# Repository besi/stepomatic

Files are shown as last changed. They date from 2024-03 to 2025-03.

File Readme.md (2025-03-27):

# Stepomatic

Wifi-enabled 28BYJ-48 stepper motor driver.

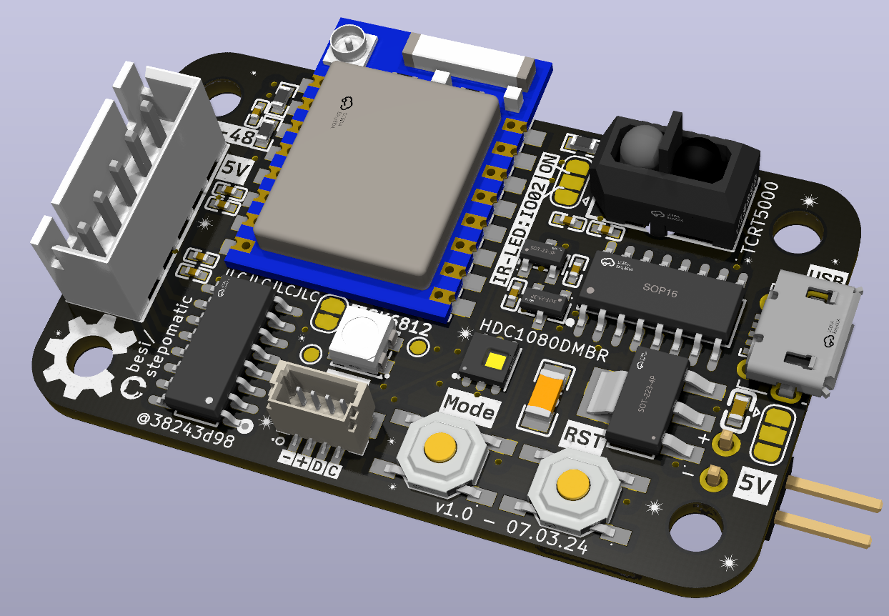
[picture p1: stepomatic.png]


## Pinout

| Function | Pin |
|:---|---:|
| Motor 1 | 13 |
| Motor 2 | 12 |
| Motor 3 | 14 |
| Motor 4 | 15 |
| SDA | 4 |
| SCL | 5 |
| Mode | 0 |
| Neopixel | 16 |
| Enable IR  | 2 |
| Distance | ADC(0) |

The IR diode can be enabled by pulling `IO2` to `0`.

The SDA and SCL need to be pulled high in software.

## Flashing

The used ESP-07 chip uses 1MB of flash so make sure to flash it with the [1MB flash image](https://micropython.org/download/ESP8266_GENERIC/).

## JLC Componennts

    # Put this in your ~/.zshrc or ~/.bashrc
    alias jlc='JLC2KiCadLib -dir lib'
    
    # Now the following will download kicad symbols, footprints and 3d models
    jlc C82227

## Acknowledgments

- Special thanks to Valentyna M. for designing the pcb artwork.
- The free font [Dexotick](https://www.behance.net/dhanstudio) was used for the pcb artwork.
- [JLC2KiCadLib](https://pypi.org/project/JLC2KiCadLib) was used for downloading the footprints for the LCSC footprints

## Known issues

The Neopixel on Pin 16 does not work since that Pin has some limitations and neither supports PWM or I2C.

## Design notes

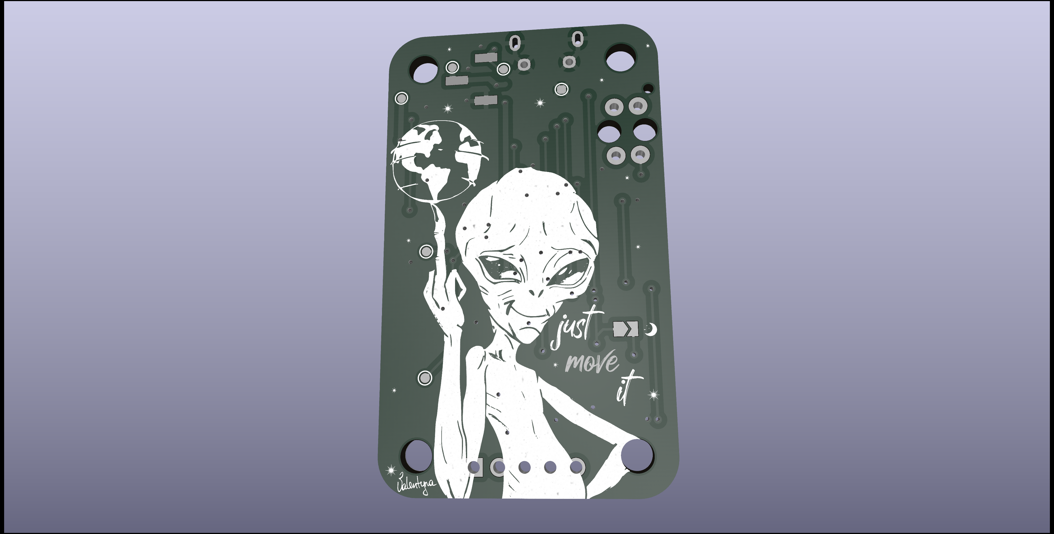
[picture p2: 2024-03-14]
stepomatic-back.png

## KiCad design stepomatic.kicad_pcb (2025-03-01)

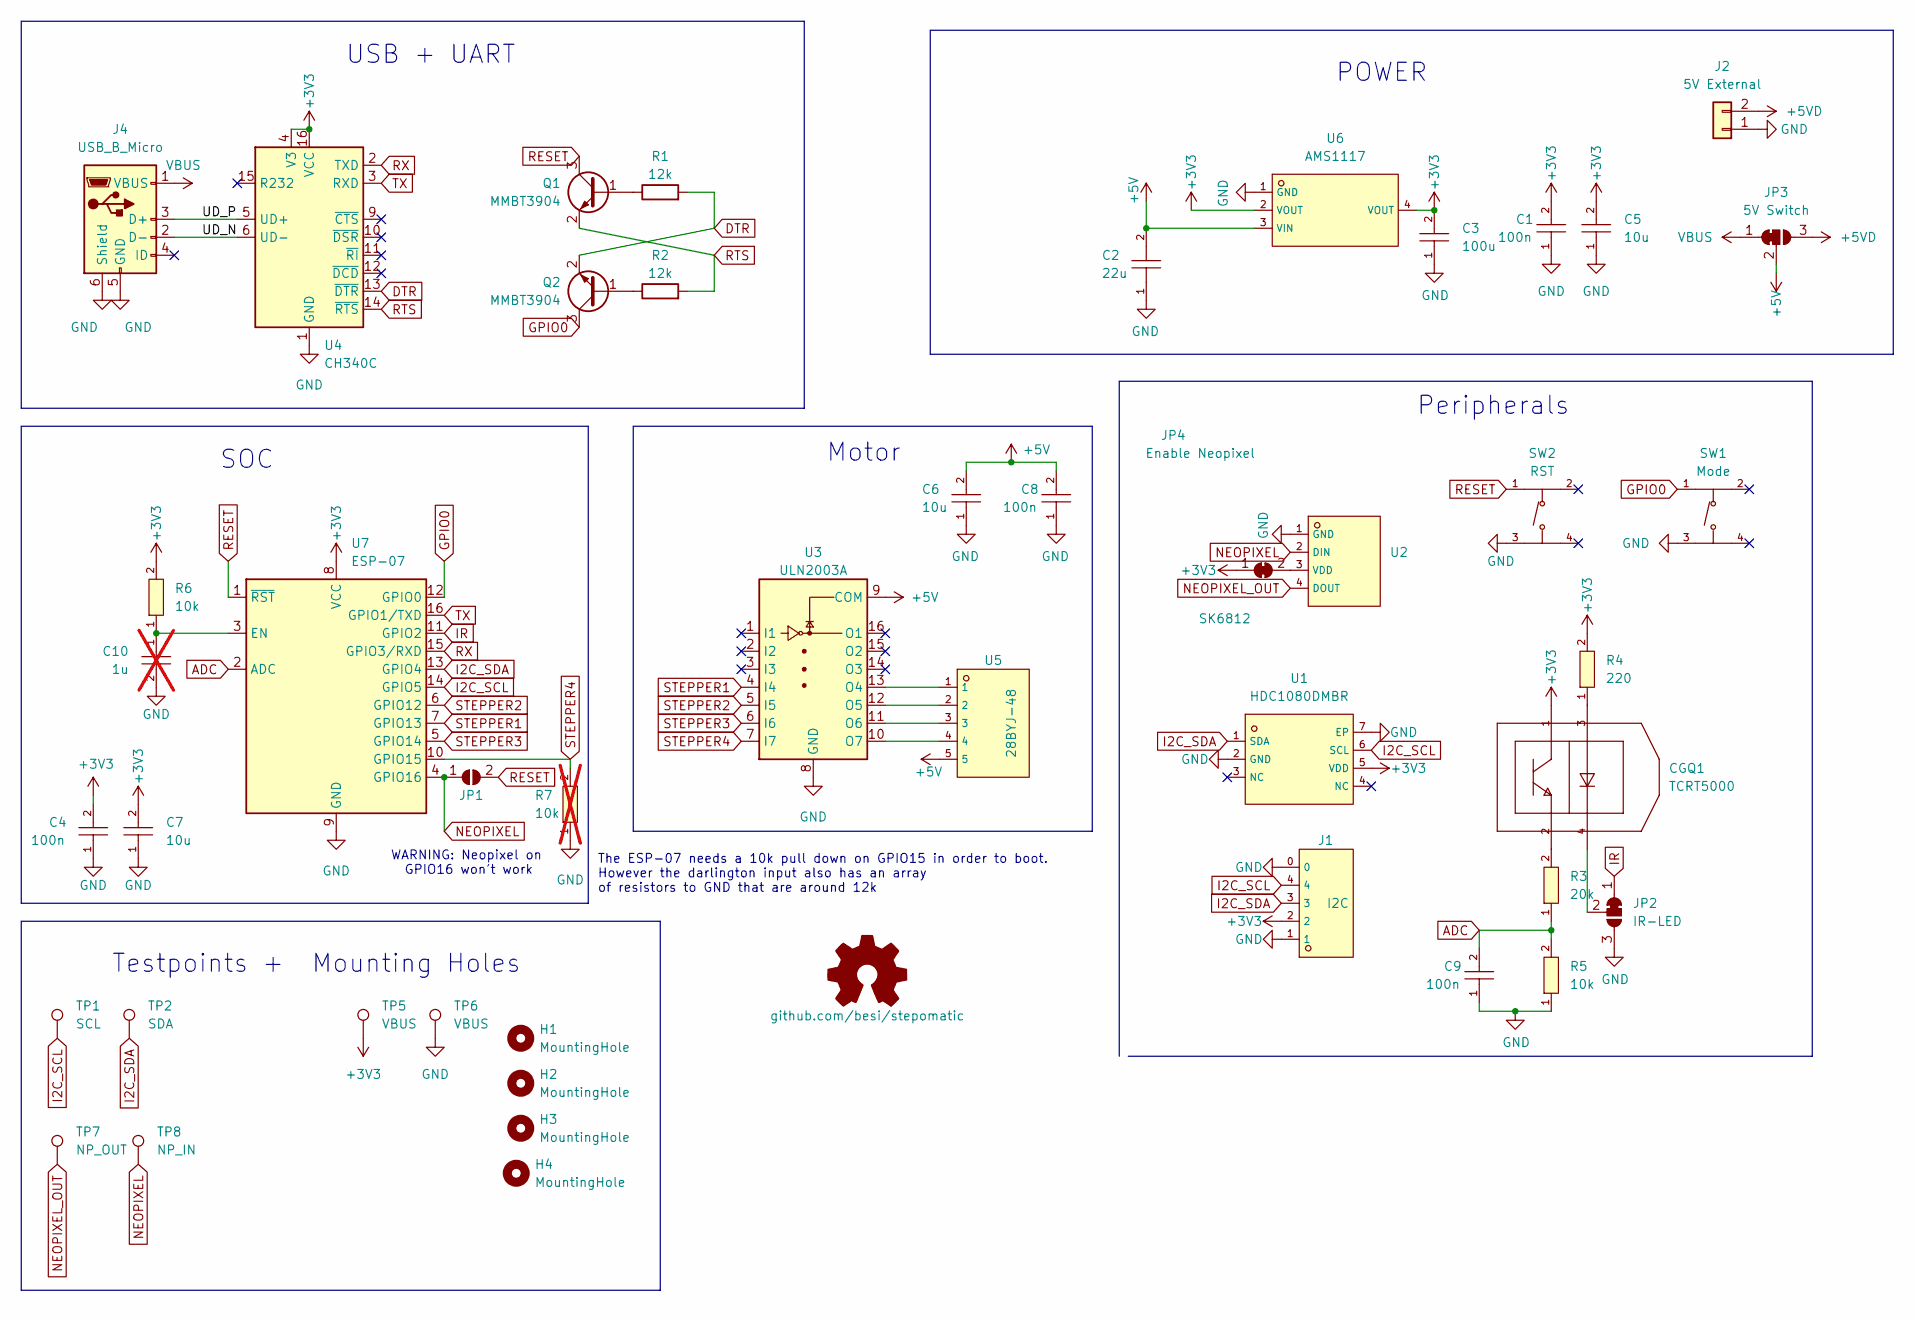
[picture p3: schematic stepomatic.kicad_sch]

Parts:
C1, C4, C8, C9: 100n; C0402; LCSC C1525
C2: 22u; C0603; LCSC C59461
C3: 100u; C1206; LCSC C15008
C5, C6, C7: 10u; C0402; LCSC C15525
C10: 1u; C0603; LCSC C15849; not fitted
CGQ1: TCRT5000; OPTO-TH_TCRT5000L; LCSC C24085
H1, H2, H3, H4: MountingHole; MountingHole_3.2mm_M3; LCSC DNP
J1: I2C; CONN-SMD_BM04B-SRSS-TB; LCSC C160390
J2: 5V External; PinHeader_1x02_P2.54mm_Horizontal
J4: USB_B_Micro; USB_Micro-B_Molex-105017-0001; LCSC C505111
JP1: Deep Sleep; SolderJumper-2_P1.3mm_Open_TrianglePad1.0x1.5mm; LCSC DNP
JP2: IR-LED; SolderJumper-3_P1.3mm_Bridged12_RoundedPad1.0x1.5mm
JP3: 5V Switch; SolderJumper-3_P1.3mm_Bridged12_RoundedPad1.0x1.5mm
JP4: Enable Neopixel; SolderJumper-2_P1.3mm_Bridged_RoundedPad1.0x1.5mm
OSHW1: github.com/besi/stepomatic; OSHW-Symbol_6.7x6mm_SilkScreen
Q1, Q2: MMBT3904; SOT-23-3_L2.9-W1.3-P1.90-LS2.4-BR; LCSC C20526
R1, R2: 12k; C0402; LCSC C25752
R3: 20k; R0603; LCSC C4184
R4: 220; R0603; LCSC C22962
R5, R6: 10k; R0603; LCSC C25804
R7: 10k; R0603; LCSC C25804; not fitted
SW1: Mode; SW-SMD_4P-L5.1-W5.1-P3.70-LS6.5-TL-2; LCSC C318884
SW2: RST; SW-SMD_4P-L5.1-W5.1-P3.70-LS6.5-TL-2; LCSC C318884
TP1: SCL; TestPoint_Pad_D1.0mm
TP2: SDA; TestPoint_Pad_D1.0mm
TP5, TP6: VBUS; TestPoint_Pad_D1.0mm
TP7: NP_OUT; TestPoint_Pad_D1.0mm
TP8: NP_IN; TestPoint_Pad_D1.0mm
U1: HDC1080DMBR; SENSOR-SMD_HDC1080DMBR; LCSC C82227
U2: SK6812; LED-SMD_4P-L3.5-W3.5-BR_SK6812MINI-HS; LCSC C2922787
U3: ULN2003A; SOIC-16_L9.9-W3.9-P1.27-LS6.0-BL; LCSC C7512
U4: CH340C; SOP-16_L10.0-W3.9-P1.27-LS6.0-BL; LCSC C7464026
U5: 28BYJ-48; CONN-TH_B5B-XH-A-LF-SN; LCSC C157991
U6: AMS1117; SOT-223-3_L6.5-W3.4-P2.30-LS7.0-BR; LCSC C6186
U7: ESP-07; WIFIM-SMD_ESP-07; LCSC C82894

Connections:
+3V3: C1.2, C3.2, C4.2, C5.2, C7.2, CGQ1.1 (C), J1.2, JP4.1 (A), R4.2, R6.2, TP5.1, U1.5 (VDD), U4.4 (V3), U4.16 (VCC), U6.2 (VOUT), U6.4 (VOUT), U7.8 (VCC)
+5V: C2.2, C6.2, C8.2, JP3.2 (C), U3.9 (COM), U5.5, U6.3 (VIN)
+5VD: J2.2, JP3.3 (B)
/UD_N: J4.2 (D-), U4.6 (UD-)
/UD_P: J4.3 (D+), U4.5 (UD+)
ADC: C9.2, R3.1, R5.2, U7.2 (ADC)
DTR: Q2.2 (E), R1.2, U4.13 (~DTR)
GND: C1.1, C2.1, C3.1, C4.1, C5.1, C6.1, C7.1, C8.1, C9.1, C10.2, J1.0, J1.1, J2.1, J4.5 (GND), J4.6 (Shield), JP2.3 (B), R5.1, R7.1, SW1.3 (C), SW2.3 (C), TP6.1, U1.2 (GND), U1.7 (EP), U2.1 (GND), U3.8 (GND), U4.1 (GND), U6.1 (GND), U7.9 (GND)
GPIO0: Q2.3 (C), SW1.1 (A), U7.12 (GPIO0)
I2C_SCL: J1.4, TP1.1, U1.6 (SCL), U7.14 (GPIO5)
I2C_SDA: J1.3, TP2.1, U1.1 (SDA), U7.13 (GPIO4)
IR: JP2.1 (A), U7.11 (GPIO2)
NEOPIXEL: JP1.1 (A), TP8.1, U2.2 (DIN), U7.4 (GPIO16)
NEOPIXEL_OUT: TP7.1, U2.4 (DOUT)
unnamed: CGQ1.3 (A), R4.1
unnamed: CGQ1.2 (E), R3.2
unnamed: CGQ1.4 (C), JP2.2 (C)
unnamed: JP4.2 (B), U2.3 (VDD)
unnamed: Q1.1 (B), R1.1
unnamed: Q2.1 (B), R2.1
unnamed: U3.13 (O4), U5.1
unnamed: U3.12 (O5), U5.2
unnamed: U3.11 (O6), U5.3
unnamed: U3.10 (O7), U5.4
unnamed: C10.1, R6.1, U7.3 (EN)
RESET: JP1.2 (B), Q1.3 (C), SW2.1 (A), U7.1 (~RST)
RTS: Q1.2 (E), R2.2, U4.14 (~RTS)
RX: U4.2 (TXD), U7.15 (GPIO3/RXD)
STEPPER1: U3.4 (I4), U7.7 (GPIO13)
STEPPER2: U3.5 (I5), U7.6 (GPIO12)
STEPPER3: U3.6 (I6), U7.5 (GPIO14)
STEPPER4: R7.2, U3.7 (I7), U7.10 (GPIO15)
TX: U4.3 (RXD), U7.16 (GPIO1/TXD)
VBUS: J4.1 (VBUS), JP3.1 (A)

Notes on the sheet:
WARNING: Neopixel on GPIO16 won't work
POWER
USB + UART
Peripherals
The ESP-07 needs a 10k pull down on GPIO15 in order to boot. However the darlington input also has an array of resistors to GND that are around 12k
Motor
SOC
Testpoints + Mounting Holes

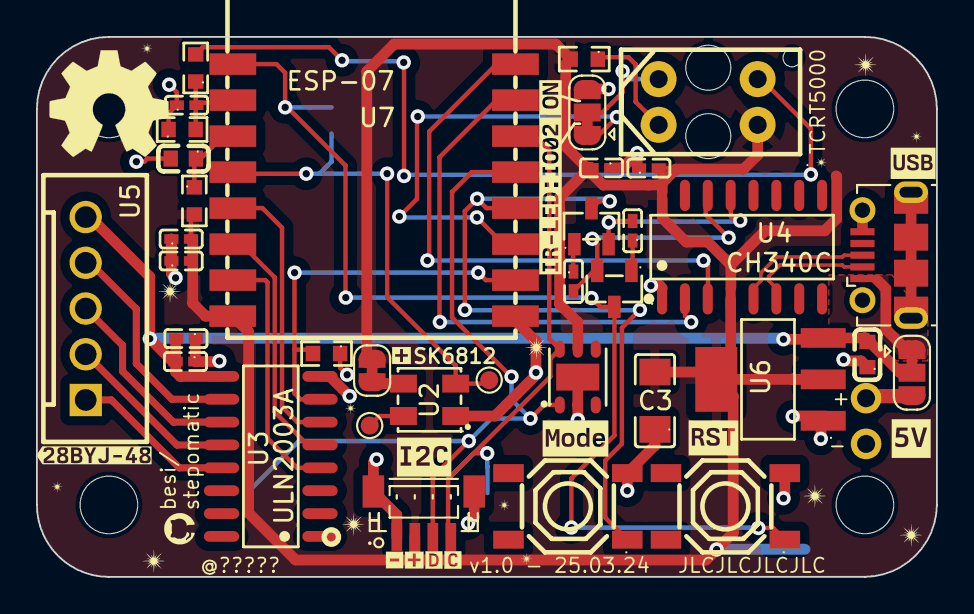
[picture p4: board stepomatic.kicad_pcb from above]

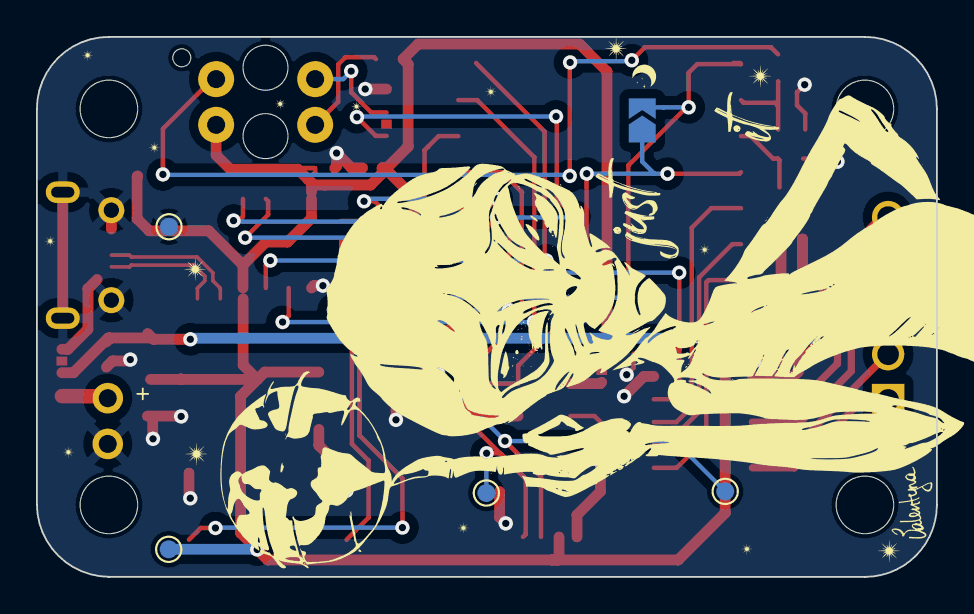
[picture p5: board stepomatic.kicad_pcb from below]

Board: 2 copper layers, 50.0 x 30.0 mm, 59 parts (6 on the bottom side), 34 nets.

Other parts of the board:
kibuzzard-65D87D0C: G***; kibuzzard-65D87D0C
kibuzzard-65D87D4C: G***; kibuzzard-65D87D4C
kibuzzard-65D87D42: G***; kibuzzard-65D87D42
kibuzzard-65D87D58: G***; kibuzzard-65D87D58
kibuzzard-65D87D77: G***; kibuzzard-65D87D77
kibuzzard-65DB2C8E: G***; kibuzzard-65DB2C8E
kibuzzard-65DB2C89: G***; kibuzzard-65DB2C89
kibuzzard-65DB2C93, kibuzzard-65DB2C93#2: G***; kibuzzard-65DB2C93
kibuzzard-65DB2CAC: G***; kibuzzard-65DB2CAC
kibuzzard-65EA2F1C: G***; kibuzzard-65EA2F1C
kibuzzard-65F0E053: G***; kibuzzard-65F0E053

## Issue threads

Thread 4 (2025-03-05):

Next Gen

besi, 2025-03-05:
- [ ] Add a (detachable) hall sensor to the board in order to be able to detect a rotating cogwheel
- [ ] Think about motor mounts such as the 28-BMY48 or the [Minebea PM15S Mini 15mm ](https://de.aliexpress.com/item/1005005152436475.html?)
- [ ] swap the reset and mode button
- [ ] Allow to debug RX (maybe TX) with an external probe such as the FlipperZero
- [ ] Remove deepsleep jumper since it's power heavy
- [ ] Exchange AMS117 for the other one in [esp8266-pcb](https://github.com/besi/esp8266-pcb)
- [ ] Use a ESP32 or a bare bone ESP8266Ex
- [ ] Swap neopixel pins the current configuration does not work
- [ ] Option: Do not populate IR Receiver and add a potential light sensor with resistor to the analogue input
- [ ] Streamline 0402 vs. 0603 components
- [ ] Smaller Buttons
- [ ] Optional display on i2c port
- [ ] Use another driver:
  - [ ] TI makes the DRV777, an 7 channel motor driver that is a direct replacement for the ULN2003, with a much lower voltage drop. That's an improvement, but probably still not optimal.
  - [ ]  Maybe power two motors with a ULN2803 and more pins

besi, 2025-03-05:
@KubaO these are my notes regarding an upcoming redesign

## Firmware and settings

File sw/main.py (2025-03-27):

# ADC
from machine import Pin
from machine import ADC
adc = ADC(0)
ir = Pin(2,Pin.OUT)
ir.value(0) # Enable IR diode so that we can receive what is reflected back
print(adc.read())


# Neopixel does not currently work
import neopixel
from machine import Pin
np = neopixel.NeoPixel(Pin(16),1)
np.fill((100,100,100))
np.write()


# Read temperature and Humidity
from machine import Pin, SoftI2C
from hdc1080 import HDC1080

scl = Pin(5, Pin.IN, Pin.PULL_UP)
sda = Pin(4, Pin.IN, Pin.PULL_UP)
i2c = SoftI2C(scl,sda)
temp = HDC1080(i2c)
print(f"Temperature {temp.temperature()}°C")
print(f"Humidity {temp.humidity()}%")


# Nod hello
import machine
import time

from uln2003 import Stepper, HALF_STEP, FULL_STEP, FULL_ROTATION
from machine import Pin

stepper = Stepper(HALF_STEP, Pin(13, Pin.OUT), Pin(12, Pin.OUT), Pin(14, Pin.OUT), Pin(15, Pin.OUT), delay=.0015 )  
mode = Pin(0, Pin.IN)

ROTATIONS = 1.33333
MARGIN = 0.9
ACTIVE = 0

dir = 1
stepper.step(FULL_ROTATION/10, dir)
dir = dir * -1
stepper.step(FULL_ROTATION/10, dir)

while True:
    # Rotate in steps
    # Change direction when button is pressed
    stepper.step(FULL_ROTATION/10, dir)
    time.sleep(1)
    if mode() == ACTIVE:
        print("Mode pressed: Change direction")
        dir = dir * -1
        time.sleep(0.4) # debounce
        

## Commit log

2024-02-10 Add components and do routing
    [stepomatic.kicad_pcb, stepomatic.kicad_sch]
2024-02-12 Prepare for jlc submission
    [stepomatic.kicad_pcb, stepomatic.kicad_sch]
2024-02-12 Add voltage divider for ADC
    [stepomatic.kicad_pcb, stepomatic.kicad_sch]
2024-02-12 Add neopixel
    [stepomatic.kicad_pcb, stepomatic.kicad_sch]
2024-02-12 Add I2C footprint
    [stepomatic.kicad_pcb, stepomatic.kicad_sch]
2024-02-12 Fix wrong capacitor
    [stepomatic.kicad_pcb, stepomatic.kicad_sch]
2024-02-12 Remove JLC property
    [stepomatic.kicad_pcb, stepomatic.kicad_sch]
2024-02-12 Fix rotation of I2C connector
    [stepomatic.kicad_pcb, stepomatic.kicad_sch]
2024-02-12 Secure 3V3 connections and change the way the ADC is read
    [stepomatic.kicad_pcb, stepomatic.kicad_sch]
2024-02-12 Add 200k because of saturation voltage of the photo transistor
    [stepomatic.kicad_pcb, stepomatic.kicad_sch]
2024-02-12 Include neopixel and fix package of C3 100uF
    [stepomatic.kicad_pcb, stepomatic.kicad_sch]
2024-02-12 Fix package of C3
    [stepomatic.kicad_pcb, stepomatic.kicad_sch]
2024-02-12 Allow to switch between ON and GPIO02 for IR send
    [stepomatic.kicad_pcb, stepomatic.kicad_sch]
2024-02-12 Tidy up
    [stepomatic.kicad_pcb, stepomatic.kicad_sch]
2024-02-12 Fix orientation of the stepper motor plug
    [stepomatic.kicad_pcb, stepomatic.kicad_sch]
2024-02-13 Tidy up for review
    [stepomatic.kicad_pcb, stepomatic.kicad_sch]
2024-02-13 Add JLC part for neopixel
    [stepomatic.kicad_sch]
2024-02-13 Add EP pad of HDC1080DMBR
    [stepomatic.kicad_pcb, stepomatic.kicad_sch]
2024-02-13 Use differential pair wiring for USB
    [stepomatic.kicad_pcb]
2024-02-13 Remove todos
    [stepomatic.kicad_pcb]
2024-02-13 Only use JLC footprints
    [stepomatic.kicad_pcb, stepomatic.kicad_sch]
2024-02-19 Add pcb artwork and some 5V caps
    [stepomatic.kicad_pcb, stepomatic.kicad_sch]
2024-02-25 Add oshw logo, silkscreen improvements capacitor for adc
    [stepomatic.kicad_pcb, stepomatic.kicad_sch]
2024-02-25 Prettify schematic
    [stepomatic.kicad_sch]
2024-02-26 Minor changes on PCB
    [stepomatic.kicad_pcb]
2024-02-27 Exclude unpopulatable components from BOM
    [stepomatic.kicad_sch]
2024-02-27 Finish up PCB backside artwork
    [stepomatic.kicad_pcb]
2024-02-28 Add artists signature
    [stepomatic.kicad_pcb]
2024-02-28 Add commit label
    [stepomatic.kicad_pcb]
2024-02-28 Clean up silkscreen
    [stepomatic.kicad_pcb]
2024-02-28 Release candidate v1.0
    [stepomatic.kicad_pcb, stepomatic.kicad_sch]
2024-03-01 Change resistors on TCRT5000 to 20k and 10k
    [stepomatic.kicad_pcb, stepomatic.kicad_sch]
2024-03-01 Add neopixel testpads
    [stepomatic.kicad_pcb, stepomatic.kicad_sch]
2024-03-01 Make IO2 the default for the TCRT5000
    [stepomatic.kicad_pcb, stepomatic.kicad_sch]
2024-03-01 Update version
    [stepomatic.kicad_pcb, stepomatic.kicad_sch]
2024-03-07 Last twaks
    Add a jumper to disable the Neopixel
    [stepomatic.kicad_pcb, stepomatic.kicad_sch]
2024-03-07 JLC Order 7.03.2024
    [stepomatic.kicad_pcb, stepomatic.kicad_sch]
2024-03-07 Exclude jumper from bom
    [stepomatic.kicad_sch]
2024-03-07 Fix name of Jumper
    [stepomatic.kicad_pcb]
2024-03-07 Add OSHW Logo
    [stepomatic.kicad_pcb, stepomatic.kicad_sch]
2024-03-07 More comprehensive 5V switch
    [stepomatic.kicad_pcb, stepomatic.kicad_sch]
2024-03-10 Pre production
    [stepomatic.kicad_pcb]
2024-03-10 Production files
    [stepomatic.kicad_pcb, stepomatic.kicad_sch]
2024-03-11 Exclude OSHW logo
    [stepomatic.kicad_pcb]
2024-03-21 Add pulldown for GPIO15
    [stepomatic.kicad_pcb, stepomatic.kicad_sch]
2024-03-21 Add commit sha
    [stepomatic.kicad_pcb, stepomatic.kicad_sch]
2024-03-21 Add a 10k pull down on GPIO15 but don’t populate it since the darlington array has a series resistance to GND of ~12k itself.
    [stepomatic.kicad_pcb, stepomatic.kicad_sch]
2024-03-25 Add a RC circuit to the EN pin
    [stepomatic.kicad_pcb, stepomatic.kicad_sch]
2024-03-25 Remove the git comment from the version section
    [stepomatic.kicad_pcb, stepomatic.kicad_sch]
2024-04-12 Add 3d rendering of the pcb
2024-05-07 Add drill origin in the center of the board
    [stepomatic.kicad_pcb]
2025-01-08 Add IR and temperature examples
2025-01-08 Added warning about neopixel
    [stepomatic.kicad_sch]
2025-03-01 Kicad 8
    [stepomatic.kicad_pcb, stepomatic.kicad_sch]
2025-03-27 Make the stepper run faster
